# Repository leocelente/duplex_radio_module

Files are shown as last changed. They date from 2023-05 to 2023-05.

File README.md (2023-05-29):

# Duplex SX126x Radio Module

Board with 2 radios, STM32 and USB or CAN

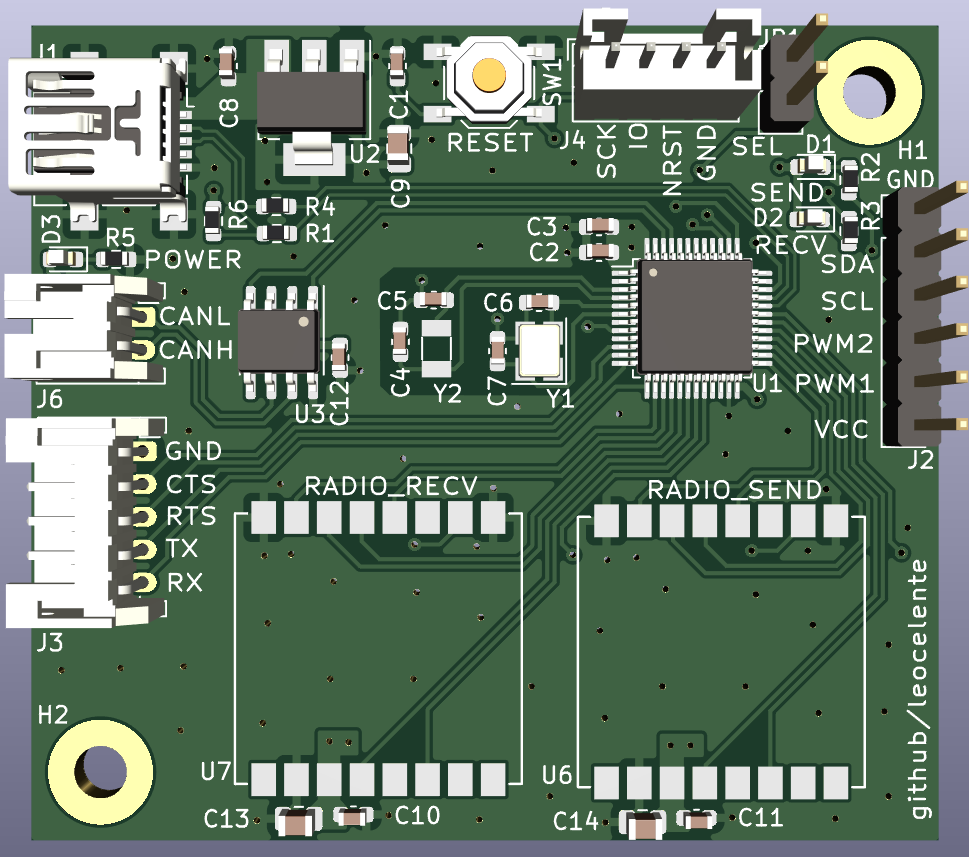
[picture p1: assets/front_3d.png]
front

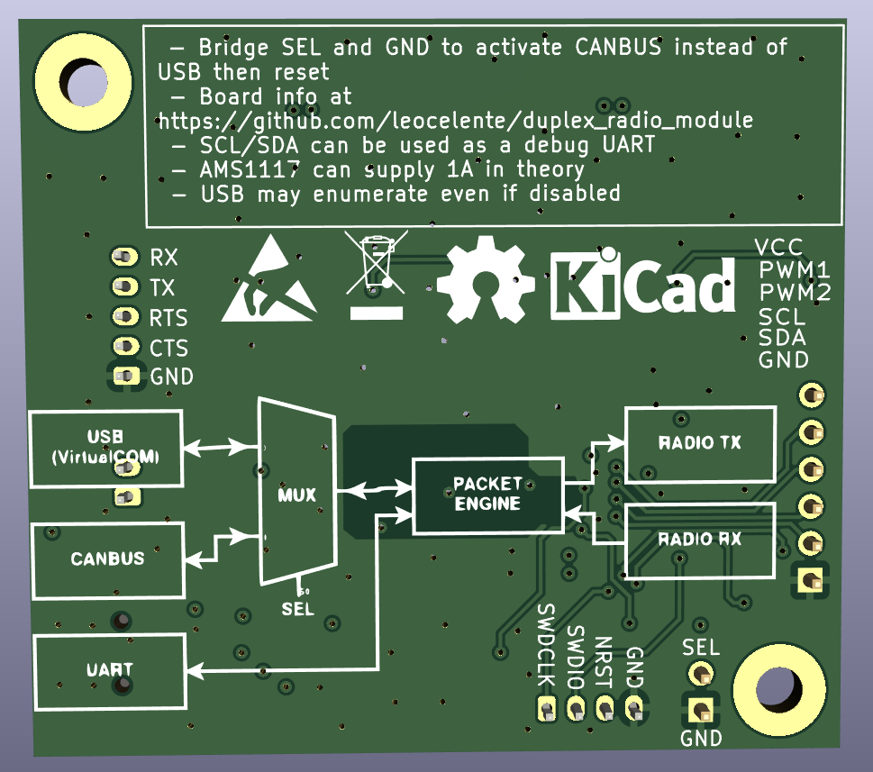
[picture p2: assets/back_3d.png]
back


## Schematic
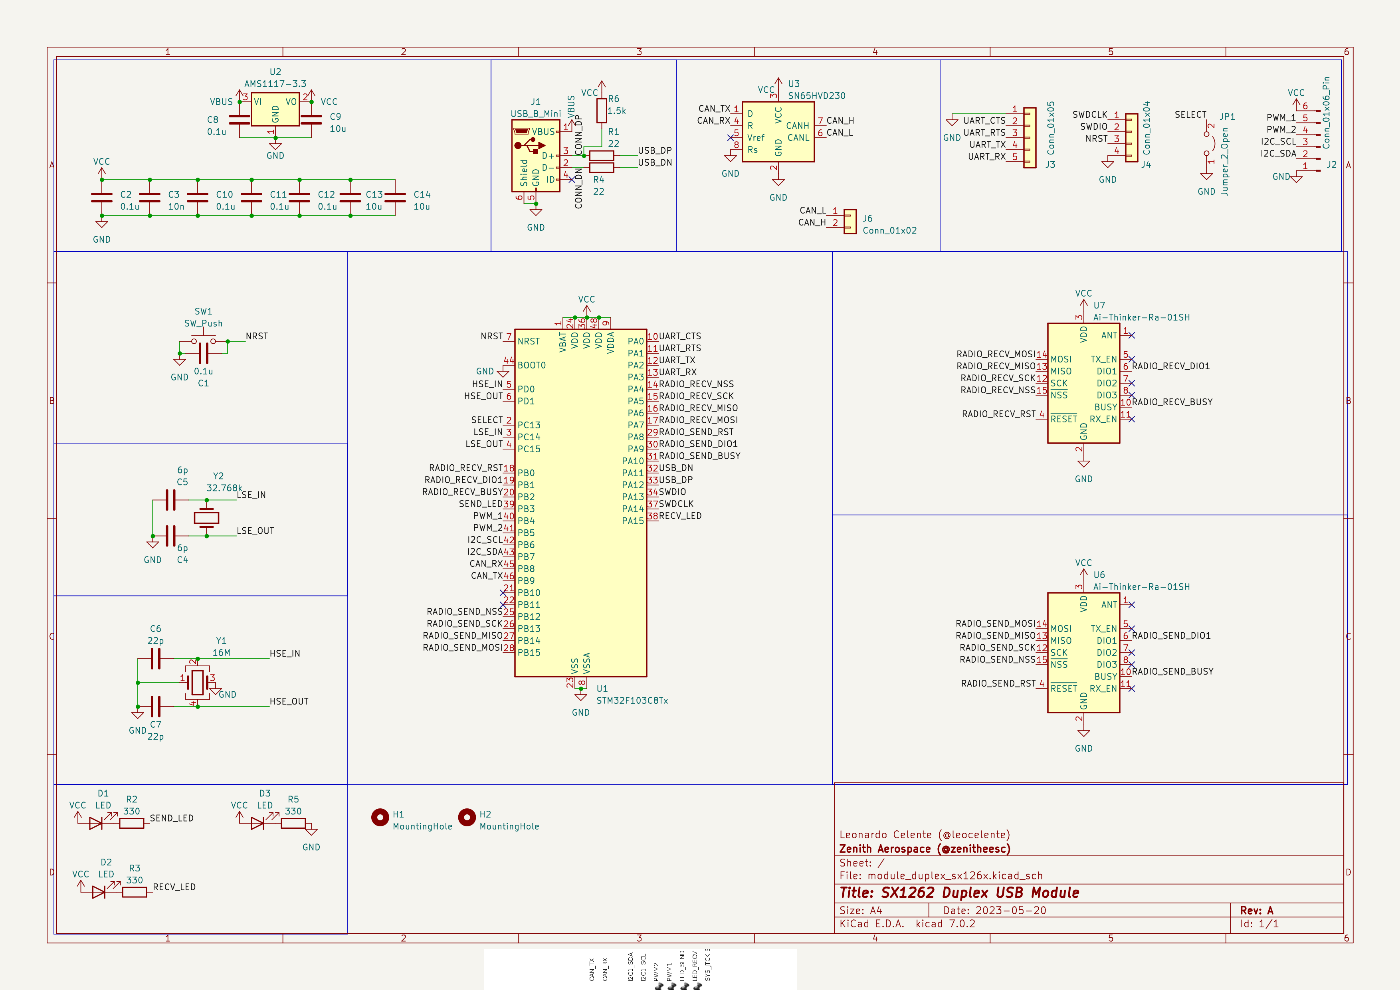
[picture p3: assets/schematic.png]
schematic


## Layout
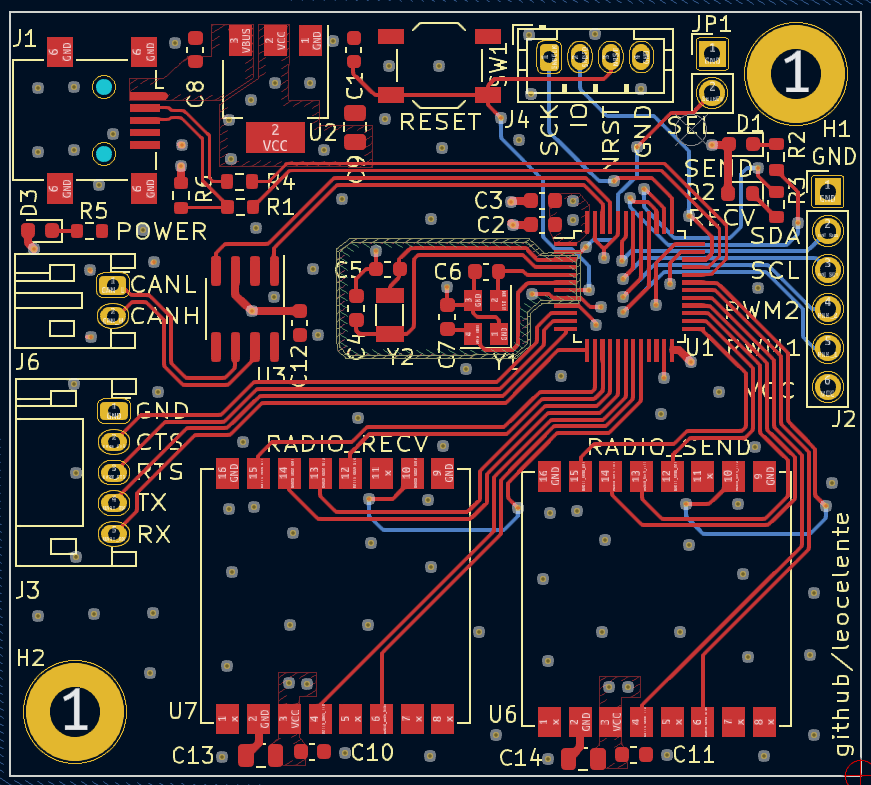
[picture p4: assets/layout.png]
layout


## Notes
The STM32F103 can't it isn't possible to use both CAN and USB 
([Source](https://community.st.com/s/article/FAQ-Concurrent-use-of-USB-and-CAN-with-STM32F103))

The intended use is to switch the interface based on the state of the SEL pin during startup process. 

## Manufacture and Assembly
The generic components and the microcontroller were chosen based on JLCPCB's Basic Parts library. That includes only the STM32, CAN transceiver, LEDs, resistors, capacitors and crystals. All connectors and the main radio modules are not included. 

| | |
|---|---|
| PCB Manufacture | $7.00 |
| PCB Assembly | $27.62 |
| Shipping | $10.17 |
| Total | $44.79 |

For 5 boards. 

Since the conversion rate of USD to BRL is around R$5,00 the cost would be R$45,00 per board. Take note that the radio module costs around R$20 on aliexpress without shipping.

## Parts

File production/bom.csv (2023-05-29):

Designator | Footprint | Quantity | Value | LCSC Part #
C1, C10, C11, C12, C2, C8 | 0603 | 6 | 0.1u | C14663
C13, C14, C9 | 0805 | 3 | 10u | C19702
C3 | 0603 | 1 | 10n | C57112
C4, C5 | 0603 | 2 | 6p | C37474
C6, C7 | 0603 | 2 | 22p | C1653
D1, D2, D3 | 0603 | 3 | LED | C72043
R1, R4 | 0603 | 2 | 22 | C23345
R2, R3, R5 | 0603 | 3 | 330 | C23138
R6 | 0603 | 1 | 1.5k | C22843
SW1 | SW_SPST_TL3342 | 1 | SW_Push | C318884
U1 | LQFP-48_7x7mm_P0.5mm | 1 | STM32F103C8Tx | C8734
U2 | SOT-223-3_TabPin2 | 1 | AMS1117-3.3 | C6186
U3 | SOIC-8_3.9x4.9mm_P1.27mm | 1 | SN65HVD230 | C12084
Y1 | Crystal_SMD_3225-4Pin_3.2x2.5mm | 1 | 16M | C13738
Y2 | Crystal_SMD_3215-2Pin_3.2x1.5mm | 1 | 32.768k | C32346

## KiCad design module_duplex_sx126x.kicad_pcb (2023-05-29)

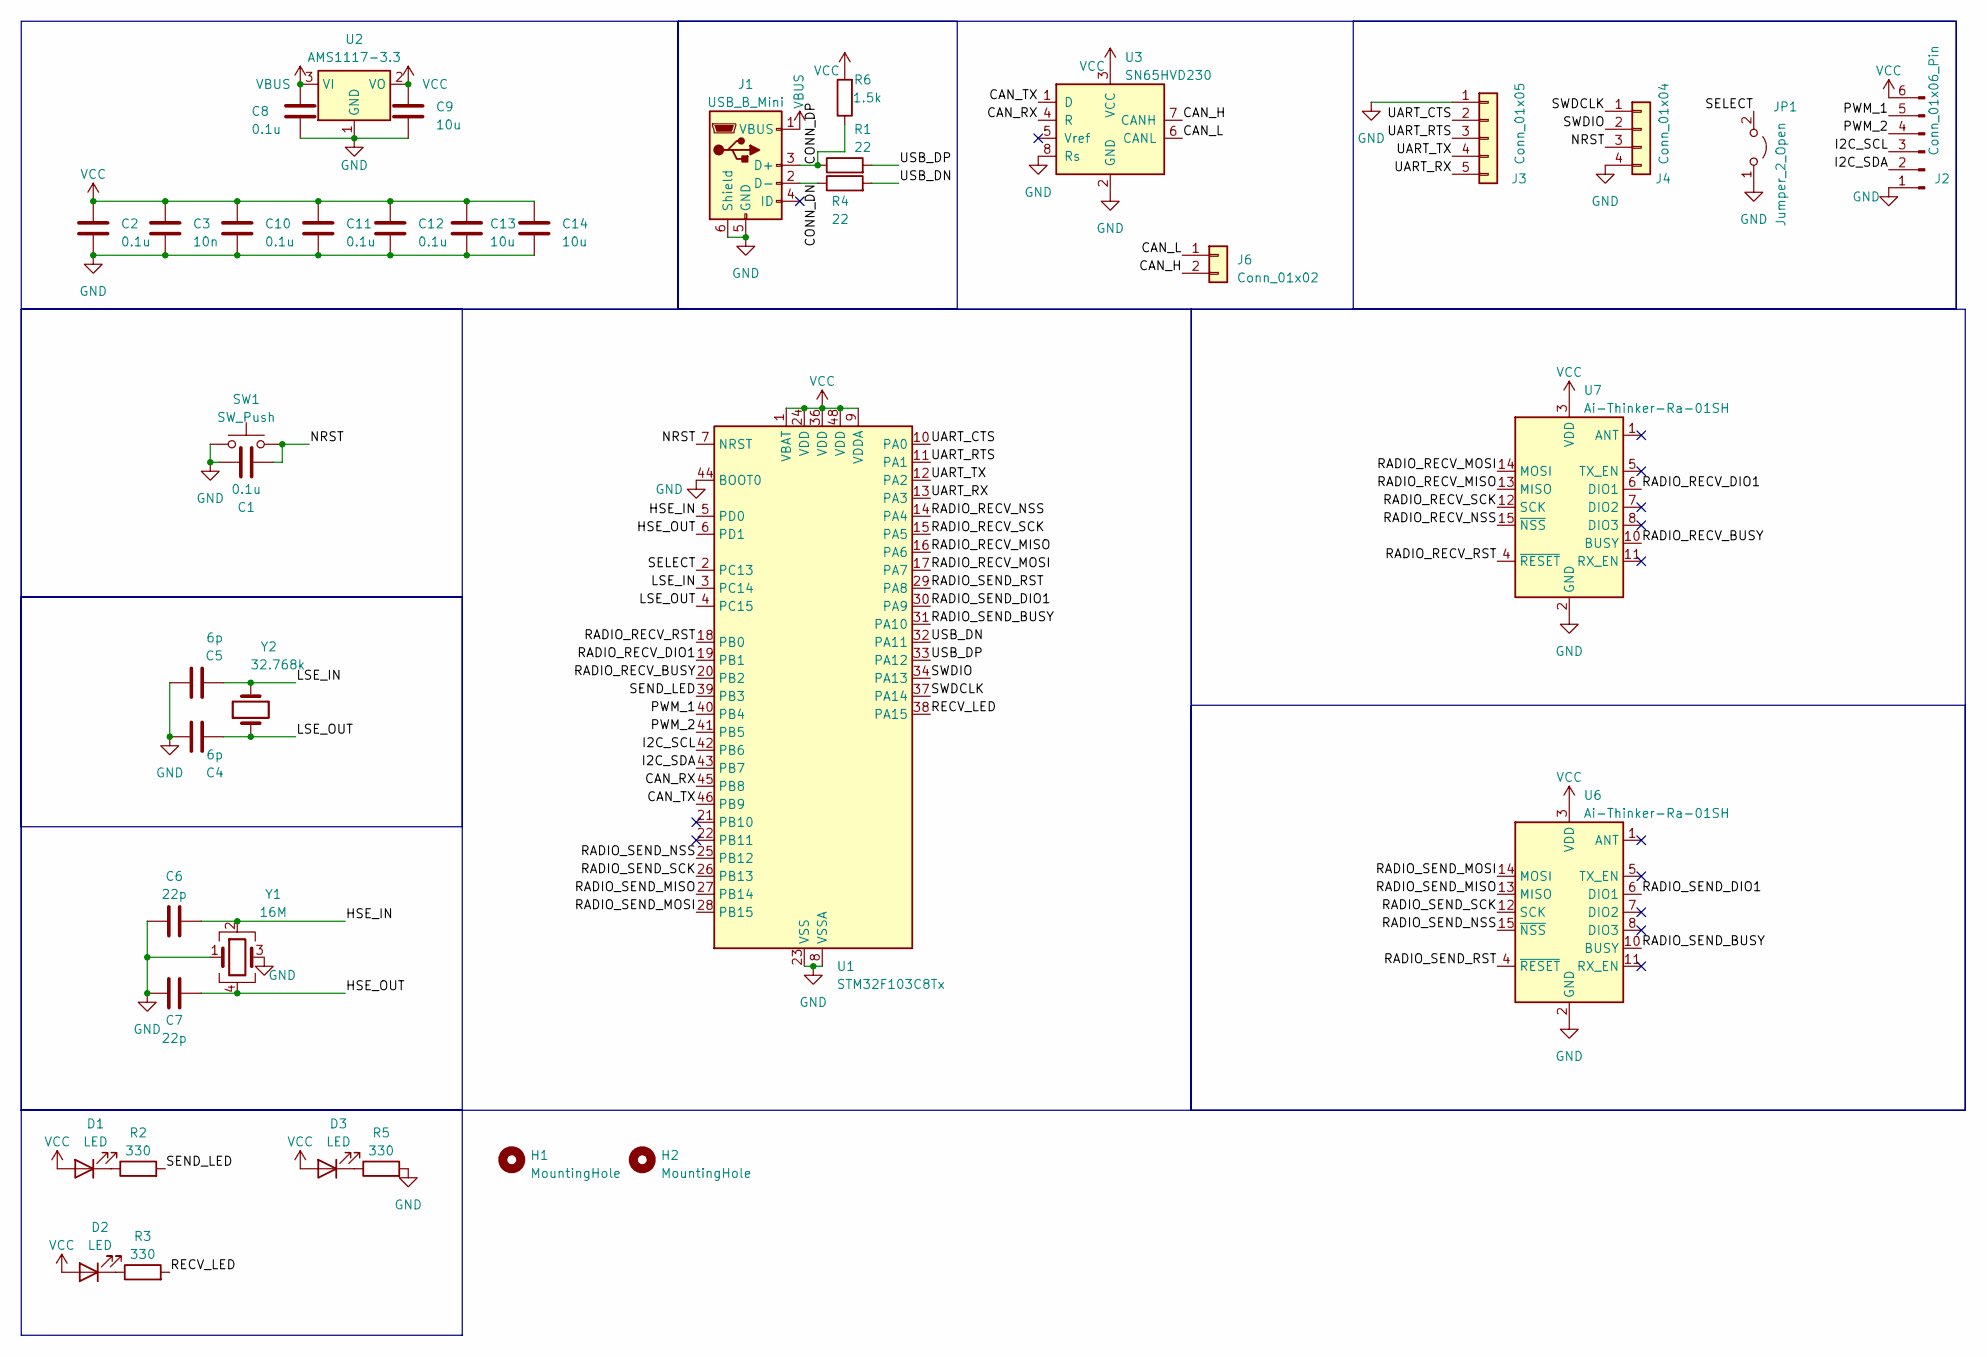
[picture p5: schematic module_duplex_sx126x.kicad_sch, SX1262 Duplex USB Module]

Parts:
C1, C2, C8, C10, C11, C12: 0.1u; C_0603_1608Metric; LCSC C14663
C3: 10n; C_0603_1608Metric; LCSC C57112
C4, C5: 6p; C_0603_1608Metric; LCSC C37474
C6, C7: 22p; C_0603_1608Metric; LCSC C1653
C9, C13, C14: 10u; C_0805_2012Metric; LCSC C19702
D1: LED; LED_0603_1608Metric; LCSC C72043
D2: LED; LED_0603_1608Metric; LCSC C72041
D3: LED; LED_0603_1608Metric; LCSC C2286
H1, H2: MountingHole; MountingHole_3.2mm_M3_Pad
J1: USB_B_Mini; USB_Mini-B_Lumberg_2486_01_Horizontal
J2: Conn_01x06_Pin; PinHeader_1x06_P2.54mm_Vertical
J3: Conn_01x05; JST_PH_S5B-PH-K_1x05_P2.00mm_Horizontal
J4: Conn_01x04; JST_PH_B4B-PH-K_1x04_P2.00mm_Vertical
J6: Conn_01x02; JST_PH_S2B-PH-K_1x02_P2.00mm_Horizontal
JP1: Jumper_2_Open; PinHeader_1x02_P2.54mm_Vertical
R1, R4: 22; R_0603_1608Metric; LCSC C23345
R2, R3, R5: 330; R_0603_1608Metric; LCSC C23138
R6: 1.5k; R_0603_1608Metric; LCSC C22843
SW1: SW_Push; SW_SPST_TL3342; LCSC C318884
U1: STM32F103C8Tx; LQFP-48_7x7mm_P0.5mm; LCSC C8734
U2: AMS1117-3.3; SOT-223-3_TabPin2; LCSC C6186
U3: SN65HVD230; SOIC-8_3.9x4.9mm_P1.27mm; LCSC C12084
U6, U7: Ai-Thinker-Ra-01SH; Ai-Thinker-Ra-01-LoRa
Y1: 16M; Crystal_SMD_3225-4Pin_3.2x2.5mm; LCSC C13738
Y2: 32.768k; Crystal_SMD_3215-2Pin_3.2x1.5mm; LCSC C32346

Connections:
/CAN_H: J6.2, U3.7 (CANH)
/CAN_L: J6.1, U3.6 (CANL)
/CAN_RX: U1.45 (PB8), U3.4 (R)
/CAN_TX: U1.46 (PB9), U3.1 (D)
/CONN_DN: J1.2 (D-), R4.1
/CONN_DP: J1.3 (D+), R1.1, R6.1
/HSE_IN: C6.2, U1.5 (PD0), Y1.2
/HSE_OUT: C7.2, U1.6 (PD1), Y1.4
/I2C_SCL: J2.3, U1.42 (PB6)
/I2C_SDA: J2.2, U1.43 (PB7)
/LSE_IN: C5.2, U1.3 (PC14), Y2.2
/LSE_OUT: C4.2, U1.4 (PC15), Y2.1
/NRST: C1.2, J4.3, SW1.2, U1.7 (NRST)
/PWM_1: J2.5, U1.40 (PB4)
/PWM_2: J2.4, U1.41 (PB5)
/RADIO_RECV_BUSY: U1.20 (PB2), U7.10 (BUSY)
/RADIO_RECV_DIO1: U1.19 (PB1), U7.6 (DIO1)
/RADIO_RECV_MISO: U1.16 (PA6), U7.13 (MISO)
/RADIO_RECV_MOSI: U1.17 (PA7), U7.14 (MOSI)
/RADIO_RECV_NSS: U1.14 (PA4), U7.15 (~NSS)
/RADIO_RECV_RST: U1.18 (PB0), U7.4 (~RESET)
/RADIO_RECV_SCK: U1.15 (PA5), U7.12 (SCK)
/RADIO_SEND_BUSY: U1.31 (PA10), U6.10 (BUSY)
/RADIO_SEND_DIO1: U1.30 (PA9), U6.6 (DIO1)
/RADIO_SEND_MISO: U1.27 (PB14), U6.13 (MISO)
/RADIO_SEND_MOSI: U1.28 (PB15), U6.14 (MOSI)
/RADIO_SEND_NSS: U1.25 (PB12), U6.15 (~NSS)
/RADIO_SEND_RST: U1.29 (PA8), U6.4 (~RESET)
/RADIO_SEND_SCK: U1.26 (PB13), U6.12 (SCK)
/RECV_LED: R3.2, U1.38 (PA15)
/SELECT: JP1.2 (B), U1.2 (PC13)
/SEND_LED: R2.2, U1.39 (PB3)
/SWDCLK: J4.1, U1.37 (PA14)
/SWDIO: J4.2, U1.34 (PA13)
/UART_CTS: J3.2, U1.10 (PA0)
/UART_RTS: J3.3, U1.11 (PA1)
/UART_RX: J3.5, U1.13 (PA3)
/UART_TX: J3.4, U1.12 (PA2)
/USB_DN: R4.2, U1.32 (PA11)
/USB_DP: R1.2, U1.33 (PA12)
GND: C1.1, C2.2, C3.2, C4.1, C5.1, C6.1, C7.1, C8.2, C9.2, C10.2, C11.2, C12.2, C13.2, C14.2, J1.5 (GND), J1.6 (Shield), J2.1, J3.1, J4.4, JP1.1 (A), R5.2, SW1.1, U1.8 (VSSA), U1.23 (VSS), U1.35 (VSS), U1.44 (BOOT0), U1.47 (VSS), U2.1 (GND), U3.2 (GND), U3.8 (Rs), U6.2 (GND), U6.9 (GND), U6.16 (GND), U7.2 (GND), U7.9 (GND), U7.16 (GND), Y1.1, Y1.3
unnamed: D1.1 (K), R2.1
unnamed: D2.1 (K), R3.1
unnamed: D3.1 (K), R5.1
VBUS: C8.1, J1.1 (VBUS), U2.3 (VI)
VCC: C2.1, C3.1, C9.1, C10.1, C11.1, C12.1, C13.1, C14.1, D1.2 (A), D2.2 (A), D3.2 (A), J2.6, R6.2, U1.1 (VBAT), U1.9 (VDDA), U1.24 (VDD), U1.36 (VDD), U1.48 (VDD), U2.2 (VO), U3.3 (VCC), U6.3 (VDD), U7.3 (VDD)

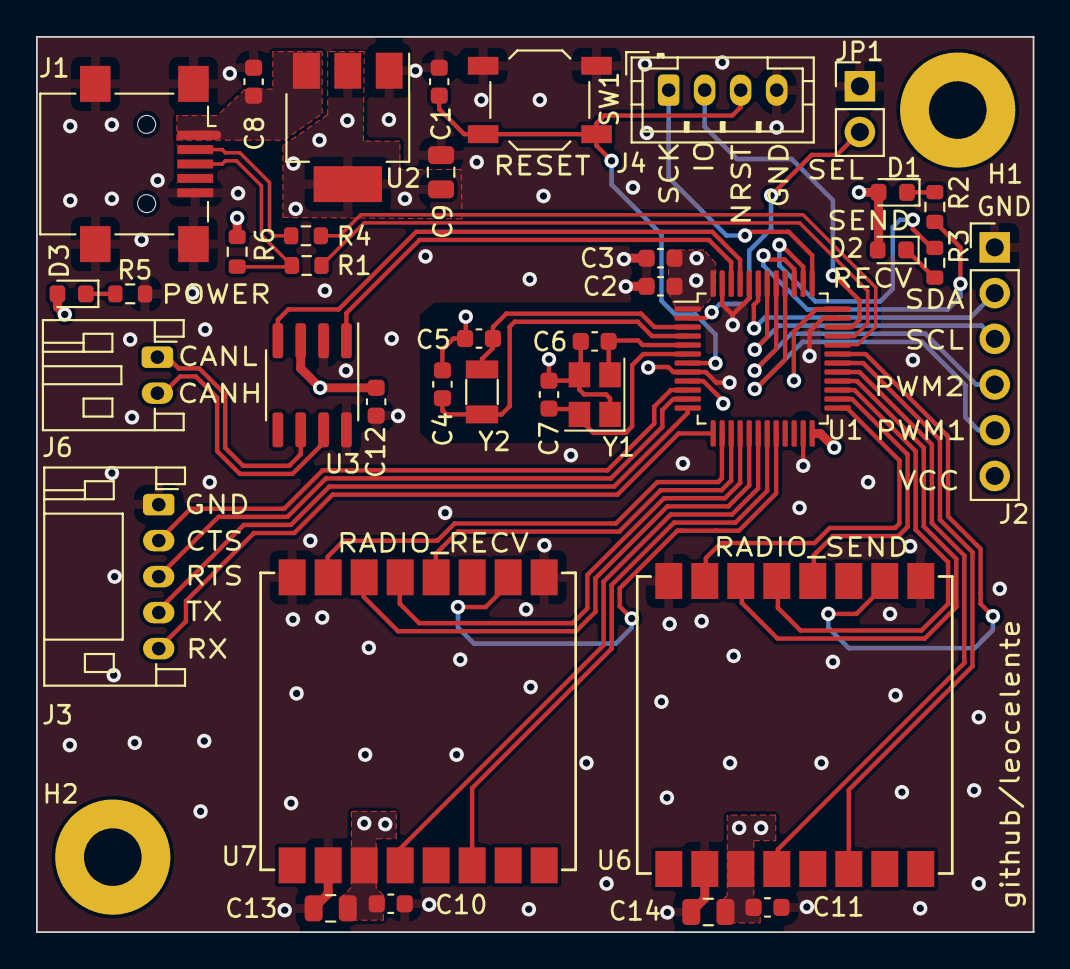
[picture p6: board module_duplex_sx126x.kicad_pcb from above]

Board: 4 copper layers, 55.4 x 49.7 mm, 39 parts (0 on the bottom side), 46 nets.

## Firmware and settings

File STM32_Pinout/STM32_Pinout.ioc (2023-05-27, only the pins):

Mcu.UserName=STM32F103C8Tx
PA0-WKUP.Signal=USART2_CTS
PA1.Signal=USART2_RTS
PA10.GPIO_Label=SPI2_INT1
PA10.Signal=GPXTI10
PA11.Signal=USB_DM
PA12.Signal=USB_DP
PA13.Signal=SYS_JTMS-SWDIO
PA14.Signal=SYS_JTCK-SWCLK
PA15.GPIO_Label=LED_RECV
PA15.Signal=GPIO_Output
PA2.Signal=USART2_TX
PA3.Signal=USART2_RX
PA4.Signal=SPI1_NSS
PA5.Signal=SPI1_SCK
PA6.Signal=SPI1_MISO
PA7.Signal=SPI1_MOSI
PA8.GPIO_Label=SPI2_RST
PA8.Signal=GPIO_Output
PA9.GPIO_Label=SPI2_TXEN
PA9.Signal=GPXTI9
PB0.GPIO_Label=SPI1_RST
PB0.Signal=GPIO_Output
PB1.GPIO_Label=SPI1_TXEN
PB1.Signal=GPXTI1
PB12.Signal=SPI2_NSS
PB13.Signal=SPI2_SCK
PB14.Signal=SPI2_MISO
PB15.Signal=SPI2_MOSI
PB2.GPIO_Label=SPI1_INT1
PB2.Signal=GPXTI2
PB3.GPIO_Label=LED_SEND
PB3.Signal=GPIO_Output
PB4.GPIO_Label=PWM1
PB4.Signal=S_TIM3_CH1
PB5.GPIO_Label=PWM2
PB5.Signal=S_TIM3_CH2
PB6.Signal=I2C1_SCL
PB7.Signal=I2C1_SDA
PB8.Signal=CAN_RX
PB9.Signal=CAN_TX
PC13-TAMPER-RTC.GPIO_Label=SELECT
PC13-TAMPER-RTC.Signal=GPIO_Input
PC14-OSC32_IN.Signal=RCC_OSC32_IN
PC15-OSC32_OUT.Signal=RCC_OSC32_OUT
PD0-OSC_IN.Signal=RCC_OSC_IN
PD1-OSC_OUT.Signal=RCC_OSC_OUT

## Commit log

2023-05-15 First Schematic and layout position
    [module_duplex_sx126x.kicad_pcb, module_duplex_sx126x.kicad_sch]
2023-05-15 Reduced expansion pins by simplifying select function with pull up/down
    [module_duplex_sx126x.kicad_pcb, module_duplex_sx126x.kicad_sch]
2023-05-15 Added USB resistors
    [module_duplex_sx126x.kicad_pcb, module_duplex_sx126x.kicad_sch]
2023-05-15 Added power indicator LED
    [module_duplex_sx126x.kicad_pcb, module_duplex_sx126x.kicad_sch]
2023-05-19 First Pass routing top copper layer
    [module_duplex_sx126x.kicad_pcb, module_duplex_sx126x.kicad_sch]
2023-05-19 Added RCC settings and USB device class
2023-05-19 First Pass of full layout
    [module_duplex_sx126x.kicad_pcb, module_duplex_sx126x.kicad_sch]
2023-05-20 Added LCSC part numbers for production
    [module_duplex_sx126x.kicad_pcb, module_duplex_sx126x.kicad_sch]
2023-05-20 Latest generated production files (using JLC Fabrication plugin)
    [bom.csv, designators.csv, positions.csv]
2023-05-20 Minor tweaks to vias
    [module_duplex_sx126x.kicad_pcb]
2023-05-20 Changed connector to jumper; Added USB DM pullup
    [module_duplex_sx126x.kicad_pcb, module_duplex_sx126x.kicad_sch]
2023-05-20 removed in-pad vias
    [module_duplex_sx126x.kicad_pcb]
2023-05-20 Production Update
    [bom.csv, designators.csv, positions.csv]
2023-05-20 Moved pull up to correct USB_DP
    [module_duplex_sx126x.kicad_pcb, module_duplex_sx126x.kicad_sch, positions.csv]
2023-05-27 Corrected DIO1 BUSY pin in radio module
    [module_duplex_sx126x.kicad_pcb, module_duplex_sx126x.kicad_sch]
2023-05-28 Added silkscreen diagram and symbols
    [module_duplex_sx126x.kicad_pcb]
2023-05-29 Updated Production and added README
    [bom.csv, designators.csv, module_duplex_sx126x.kicad_pcb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]
